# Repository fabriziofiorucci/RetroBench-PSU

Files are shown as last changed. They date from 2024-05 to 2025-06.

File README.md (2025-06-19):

# RetroBench Power Supply Unit

This project is a versatile bench power supply unit that can provide a range of DC outputs and 9VAC. The `GX16-8` connector can power Commodore retrocomputers.

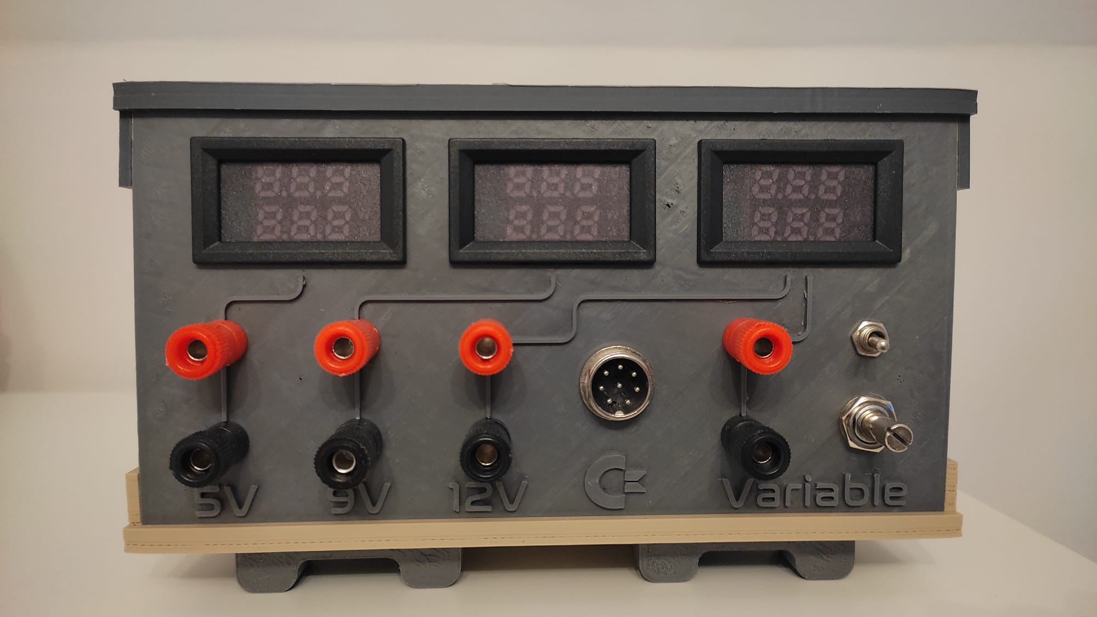
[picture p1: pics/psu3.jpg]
Front view


## Commodore retrocomputers support

The power supply has been tested with:

- Commodore VIC-20
- Commodore 16
- Commodore 64
- Commodore 128
- Commodore Amiga 500

## Bench PSU outputs

Output voltages are:

- 5VCC
- 9VCC
- 12VC
- 9VAC - through `GX16-8` connector
- Variable CC output

## 3d printed parts

STL files can be printed using:

- PLA filament
- 0.1mm layer height
- 15% infill
- 4 walls

## Parts needed

- 1x Meanwell RT-65B power supply ([link](https://www.aliexpress.com/item/1005006587968530.html))
- 1x Core transformer 220VAC to 9VAC ([link](https://www.aliexpress.com/item/4001293606204.html))
- 1x `GX16-8` male & female connectors ([link](https://www.aliexpress.com/item/1005005686517100.html))
- 4x red & black banana socket pairs ([link](https://www.aliexpress.com/item/32969822440.html))
- 1x Precision multiturn 10kOhm potentiometer ([link](https://www.aliexpress.com/item/32858999042.html))
- 1x Miniature toggle switch single pole double throw ([link](https://www.aliexpress.com/item/33012530737.html))
- 1x IEC 320 power plug socket 2.0mm AC-01-2, Copper Contact ([link](https://www.aliexpress.com/item/1005004921974470.html))
- 3x M430 10A Digital Voltmeter Ammeter ([link](https://www.aliexpress.com/item/1005002338207839.html))
- 1x MP1584EN Adjustable 3A DC-DC step down converter ([link](https://www.aliexpress.com/w/wholesale-mp1584en.html))

## GX16-8 pinout

Connector pinout (solder side):

| Pin | Description |
|-----|---|
| 1 | GND |
| 2 | +5VDC |
| 3 | +9VDC |
| 4 | +12VDC |
| 5 | -12VDC |
| 6 | 9VAC |
| 7 | 9VAC |
| 8 | Shield ground |

## Commodore pinouts

### Commodore VIC-20

7 Pin DIN connector - solder side

| Pin | Description |
|-----|---|
| 1 | GND |
| 2 | GND |
| 3 | GND |
| 4 | N/C |
| 5 | +5VDC |
| 6 | 9VAC |
| 7 | 9VAC |

### Commodore 16

Barrel connector:

- +9VDC, center negative

### Commodore 64 & 128

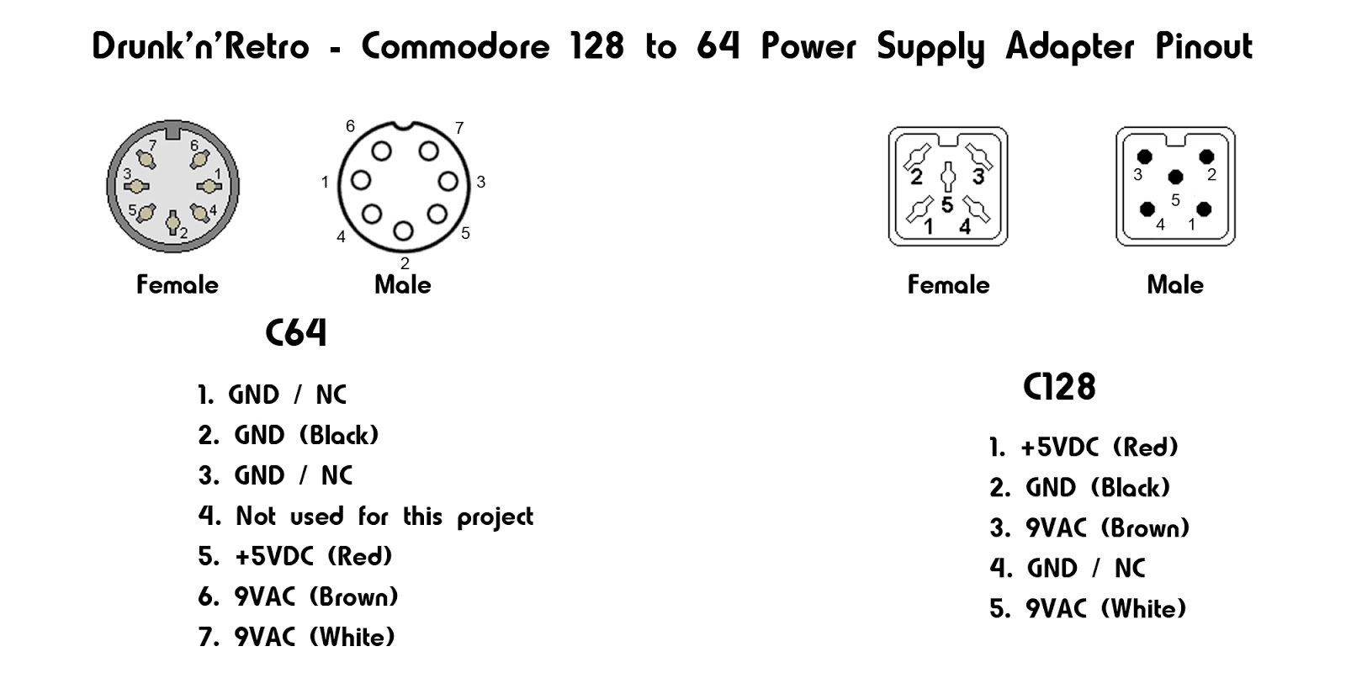
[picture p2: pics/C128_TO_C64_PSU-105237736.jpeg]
Commodore 64 & 128 pinouts


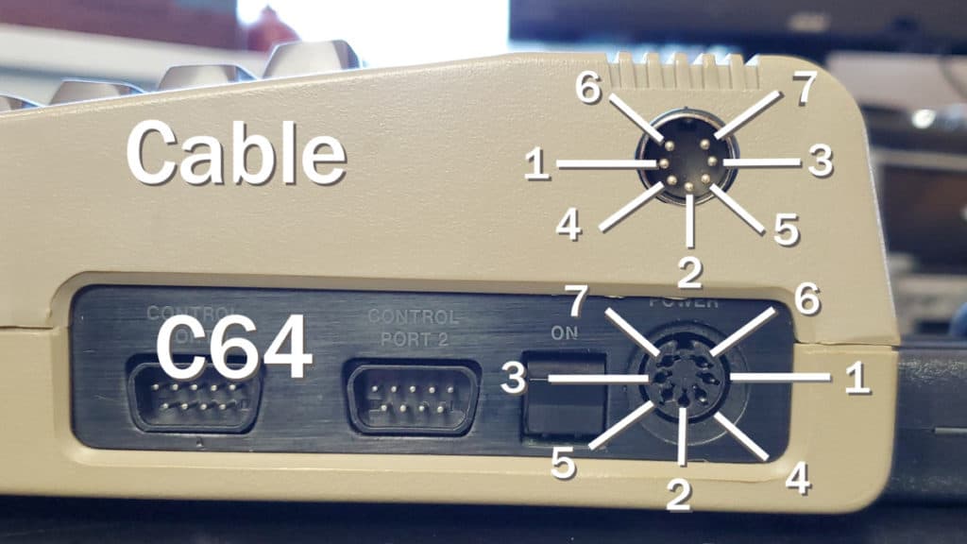
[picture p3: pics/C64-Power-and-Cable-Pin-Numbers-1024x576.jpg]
Side view


### Commodore Amiga 500

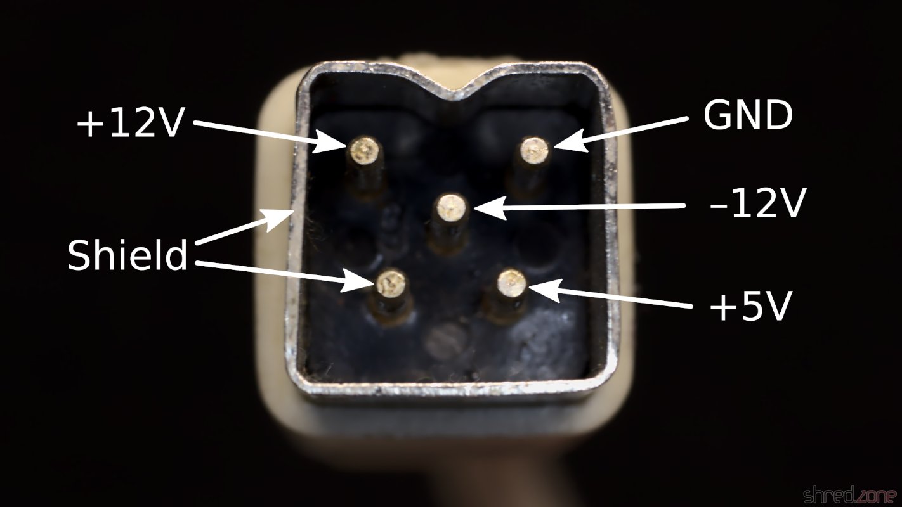
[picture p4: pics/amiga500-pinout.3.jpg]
Amiga 500 pinout


## Schematics

[WORK IN PROGRESS]

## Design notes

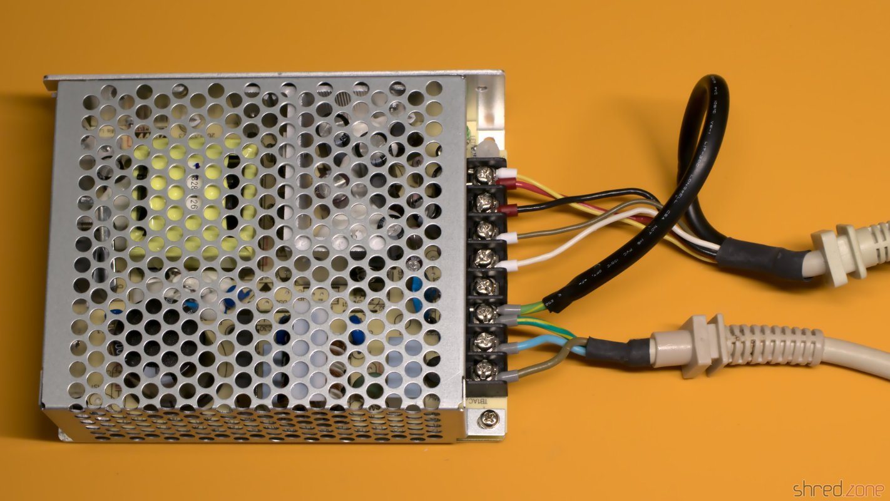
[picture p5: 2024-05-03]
pics/amiga500-pinout.1.jpg

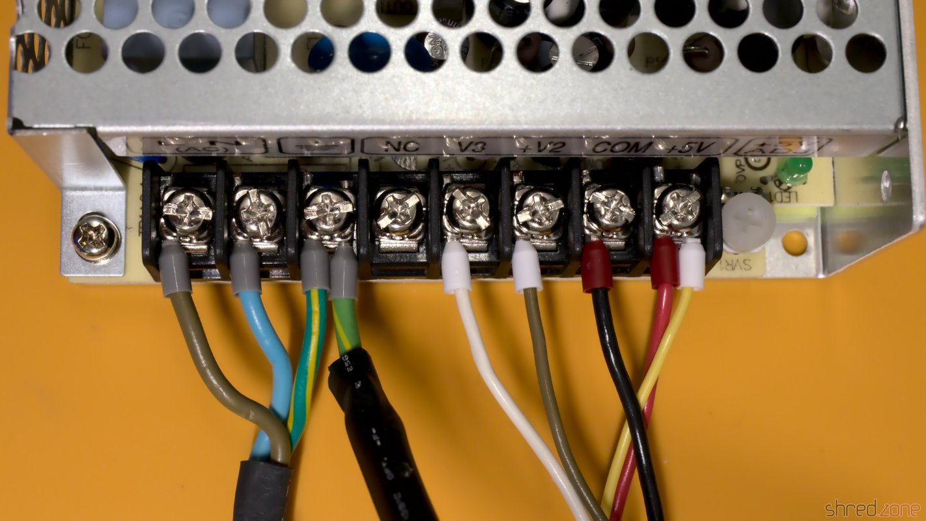
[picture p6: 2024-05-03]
pics/amiga500-pinout.2.jpg

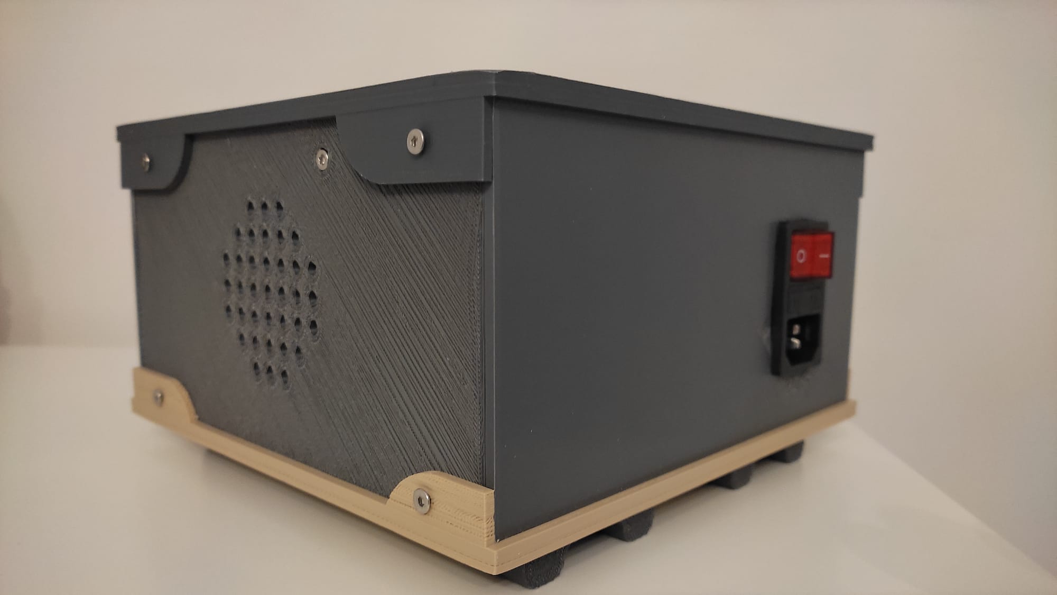
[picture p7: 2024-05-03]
pics/psu5.jpg

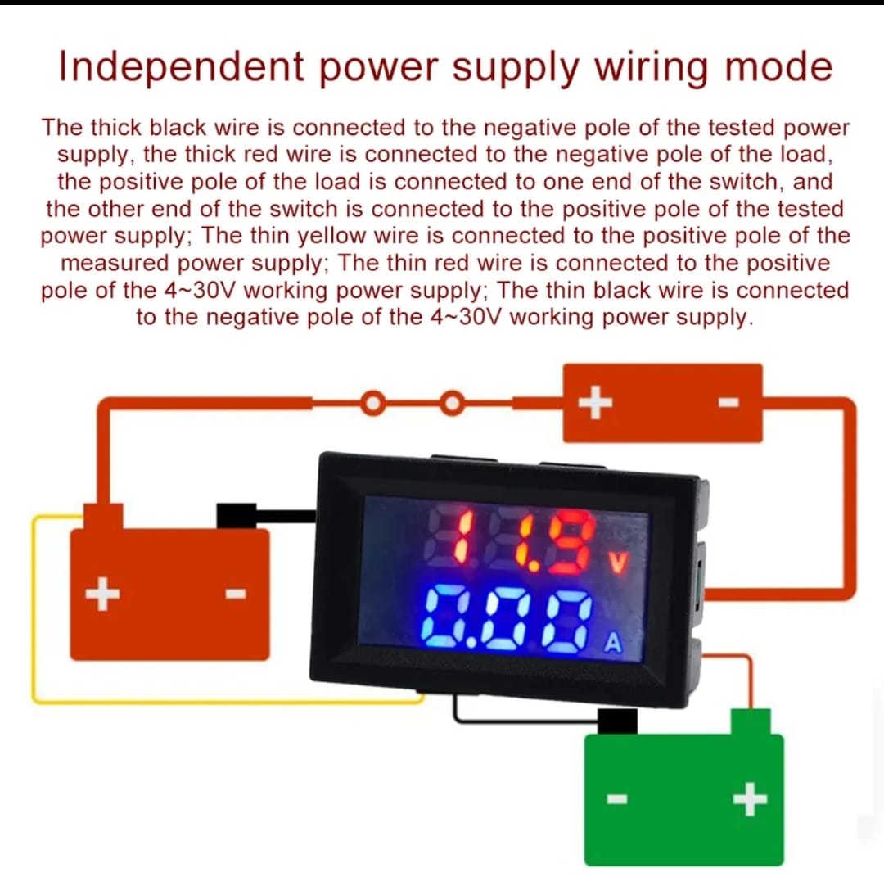
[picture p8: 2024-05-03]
pics/m430-voltmeter.jpg

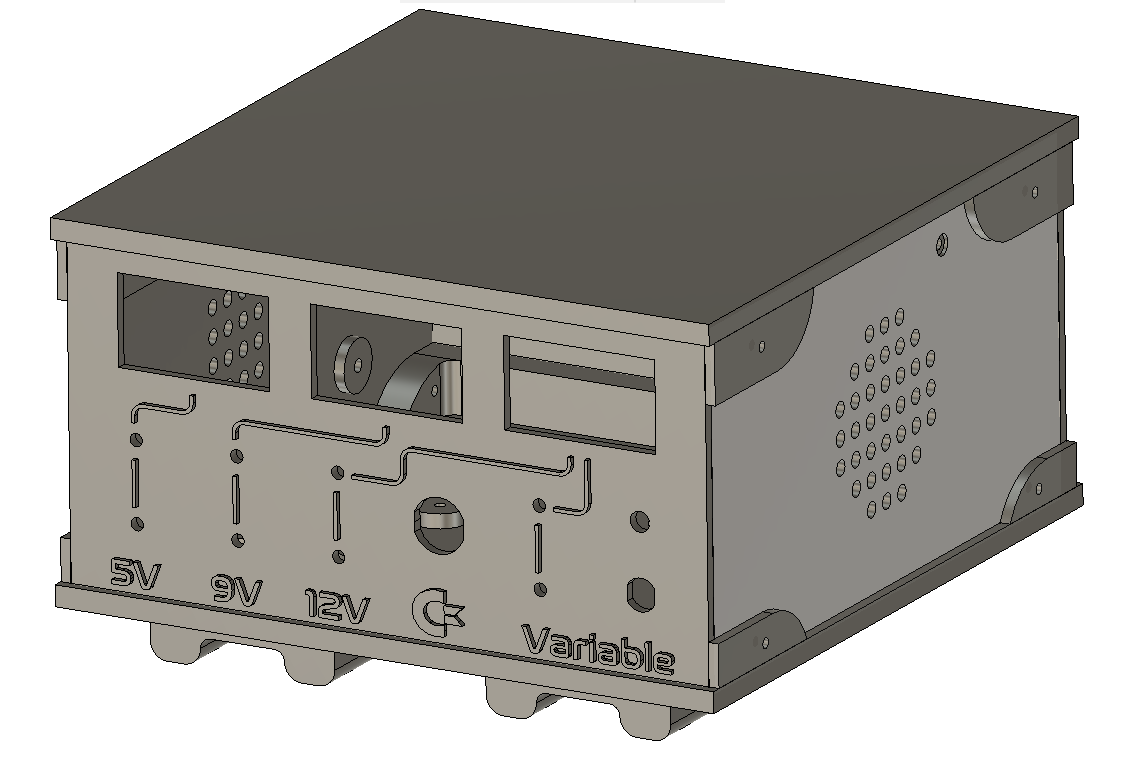
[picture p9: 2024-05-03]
pics/psu1.png

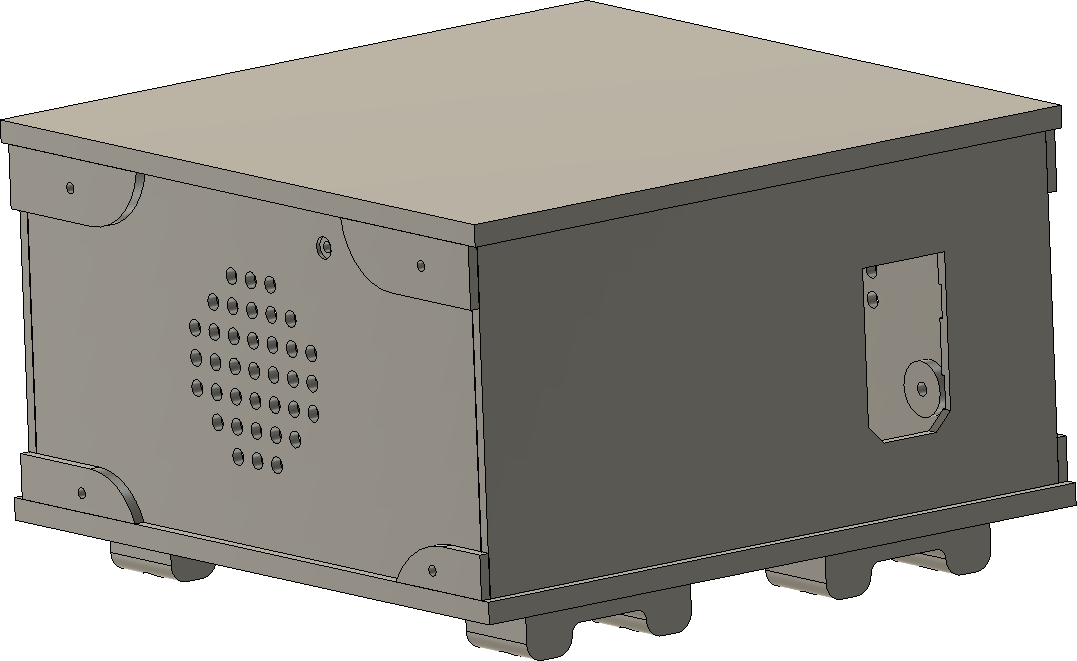
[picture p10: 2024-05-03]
pics/psu2.png

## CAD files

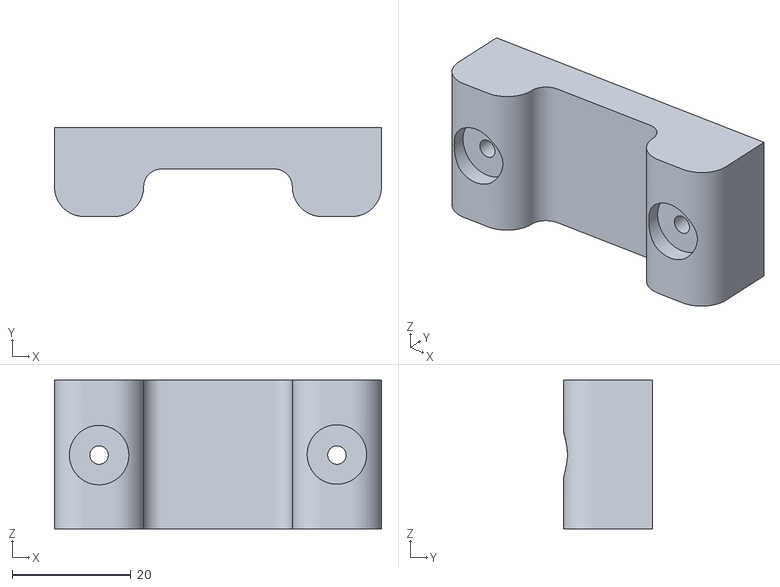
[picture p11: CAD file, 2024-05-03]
CAD/Leg 3.stl
55.0 x 15.0 x 25.0

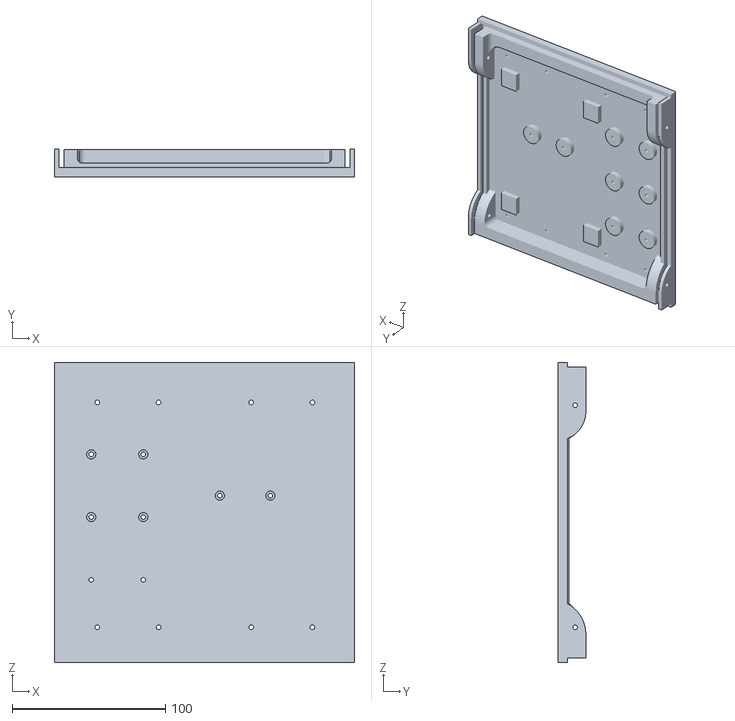
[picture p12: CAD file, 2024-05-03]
CAD/Base plate.stl
196.0 x 18.1 x 196.0

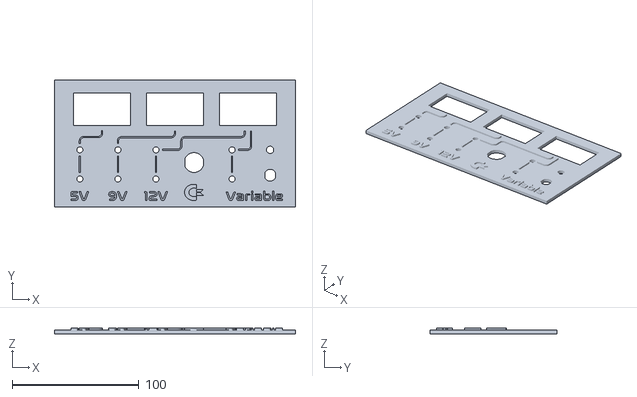
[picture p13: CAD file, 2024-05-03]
CAD/Front plate.stl
190.0 x 100.0 x 4.50

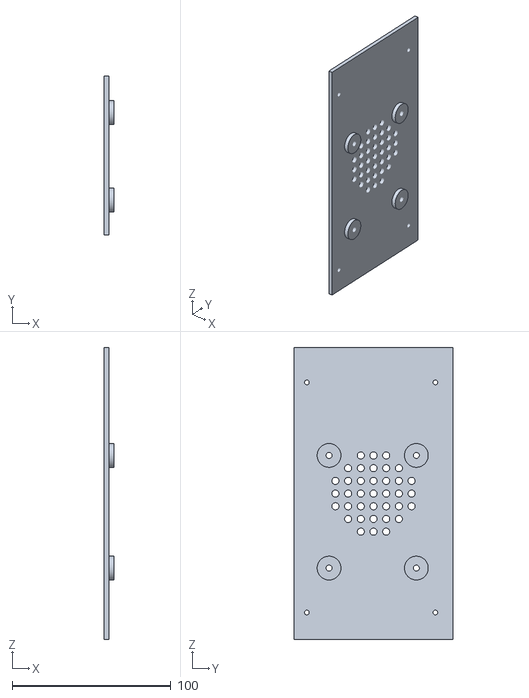
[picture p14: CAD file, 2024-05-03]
CAD/Left plate.stl
6.00 x 100.0 x 184.0

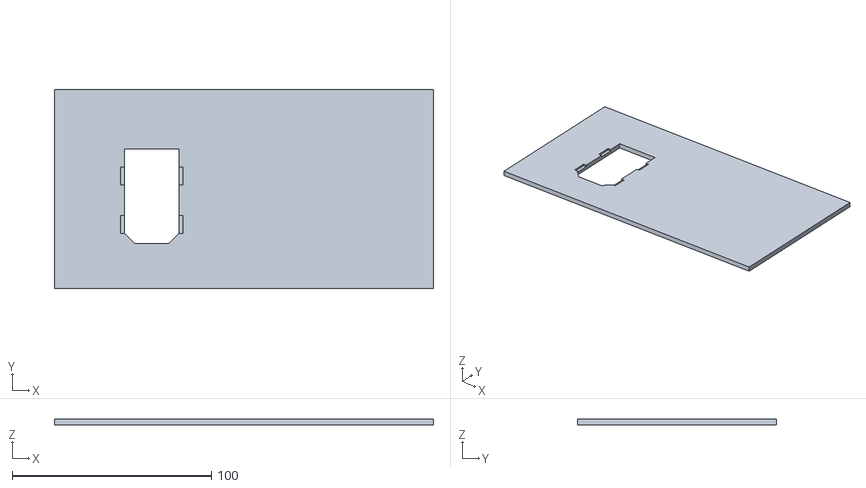
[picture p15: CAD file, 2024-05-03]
CAD/Back plate.stl
190.0 x 100.0 x 3.00

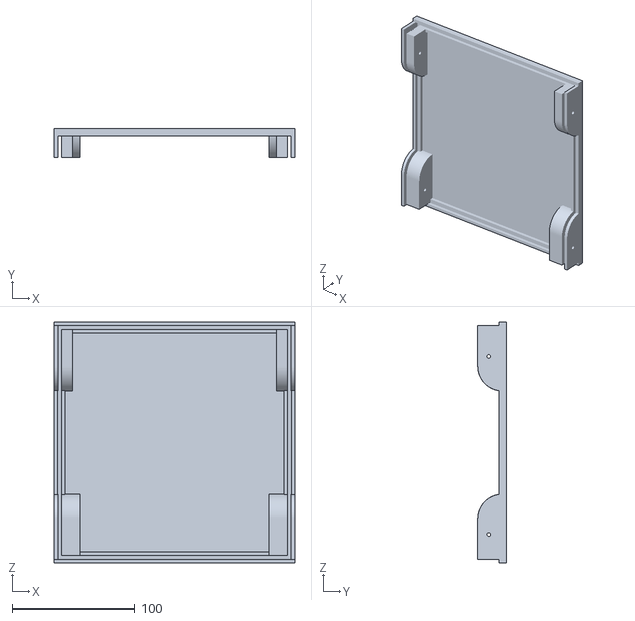
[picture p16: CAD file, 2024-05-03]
CAD/Top plate.stl
196.0 x 23.2 x 196.0

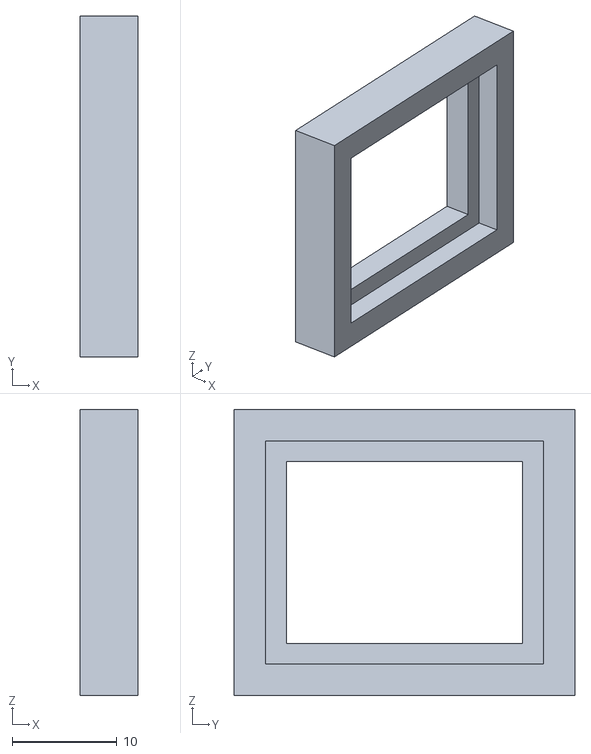
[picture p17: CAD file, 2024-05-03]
CAD/MP1584en lid.stl
5.50 x 32.5 x 27.3

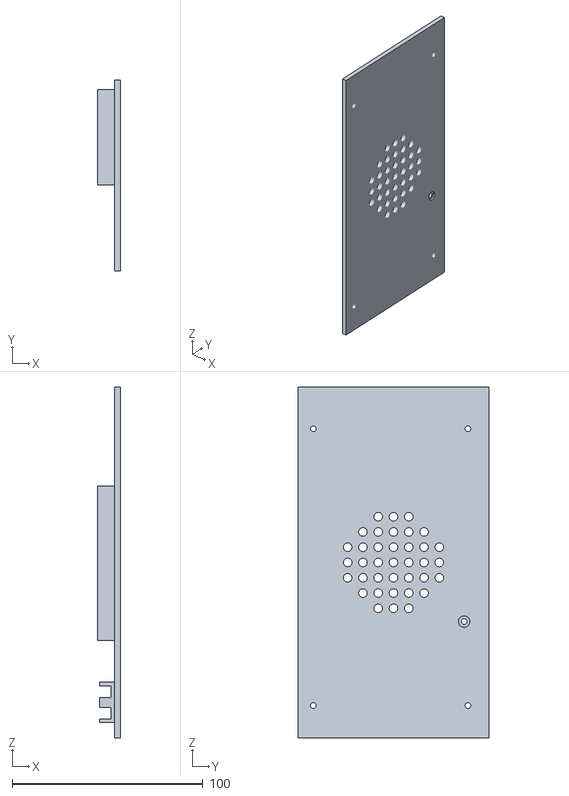
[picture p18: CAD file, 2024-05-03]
CAD/Right plate.stl
12.0 x 100.0 x 183.9

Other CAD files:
CAD/Leg 4.stl
CAD/Leg 2.stl
CAD/Leg 1.stl
